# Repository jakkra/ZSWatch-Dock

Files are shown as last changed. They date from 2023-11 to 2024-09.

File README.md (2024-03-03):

# ZSWatch-Dock




## Table of Contents

- [ZSWatch-Dock](#zswatch-dock)
  - [Table of Contents](#table-of-contents)
  - [About](#about)
  - [Configurations](#configurations)
  - [Dock connector](#dock-connector)
  - [Directory structure](#directory-structure)
  - [Purchasing](#purchasing)
  - [Maintainer](#maintainer)

## About

Programming and charging dock for the [ZSWatch](https://github.com/jakkra/ZSWatch).

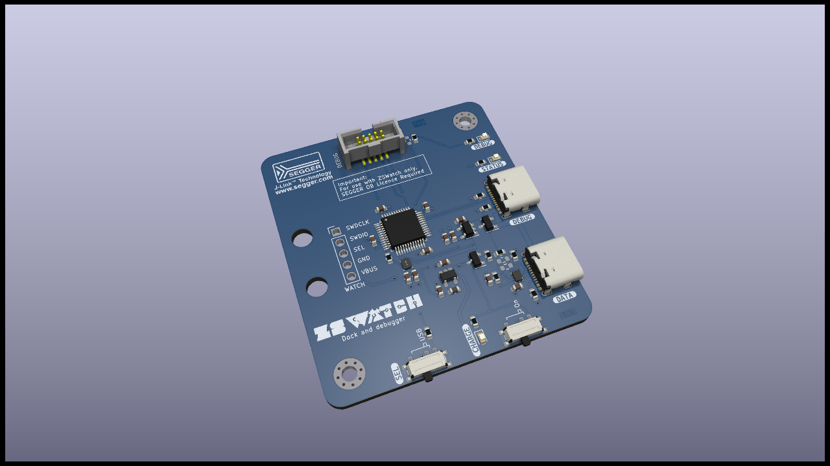
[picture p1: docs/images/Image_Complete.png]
Complete


Please check the [wiki](https://github.com/jakkra/ZSWatch/wiki) for more information about the project.

## Configurations

The dock can be used with an integrated Segger J-Link debugger or with an external Serial Wire Debugger (SWD) with an [10-pol ARM Cortex JTAG SWD](https://developer.arm.com/documentation/101416/0100/Hardware-Description/Target-Interfaces/Cortex-Debug--10-pin-) connector.

## Dock connector

The pinout for the dock connector is shown below.

<table class="tg">
<thead>
  <tr>
    <th class="tg-0pky"></th>
    <th class="tg-0pky">Pin</th>
    <th class="tg-0pky">Description</th>
  </tr>
</thead>
<tbody>
  <tr>
    <td class="tg-0pky" rowspan="5">Dock connector</td>
    <td class="tg-0pky">1</td>
    <td class="tg-0pky">VBUS (+5 V)</td>
  </tr>
  <tr>
    <td class="tg-0pky">2</td>
    <td class="tg-0pky">GND</td>
  </tr>
  <tr>
    <td class="tg-0pky">3</td>
    <td class="tg-0pky">SEL</td>
  </tr>
  <tr>
    <td class="tg-0lax">4</td>
    <td class="tg-0lax">D- / SWDIO</td>
  </tr>
  <tr>
    <td class="tg-0lax">5</td>
    <td class="tg-0lax">D+ / SWDCLK</td>
  </tr>
</tbody>
</table>

| SEL  | Function |
|---|---|
|`LOW` | USB |
|`HIGH`| SWD (Default)  |

## Directory structure

- `cad`: 3D model of the complete PCB
- `docs`: All kind of project documentation
- `project`: KiCad project for the PCB

## Purchasing

Please open `ZSWatch-Dock-navigate.html` and use the files listed under `purchasing` for ordering a PCB.

## Maintainer

- [Daniel Kampert](mailto:daniel.kameprt@kampis-elektroecke.de)
- [Jakob Krantz](mail@jakobkrantz.se)

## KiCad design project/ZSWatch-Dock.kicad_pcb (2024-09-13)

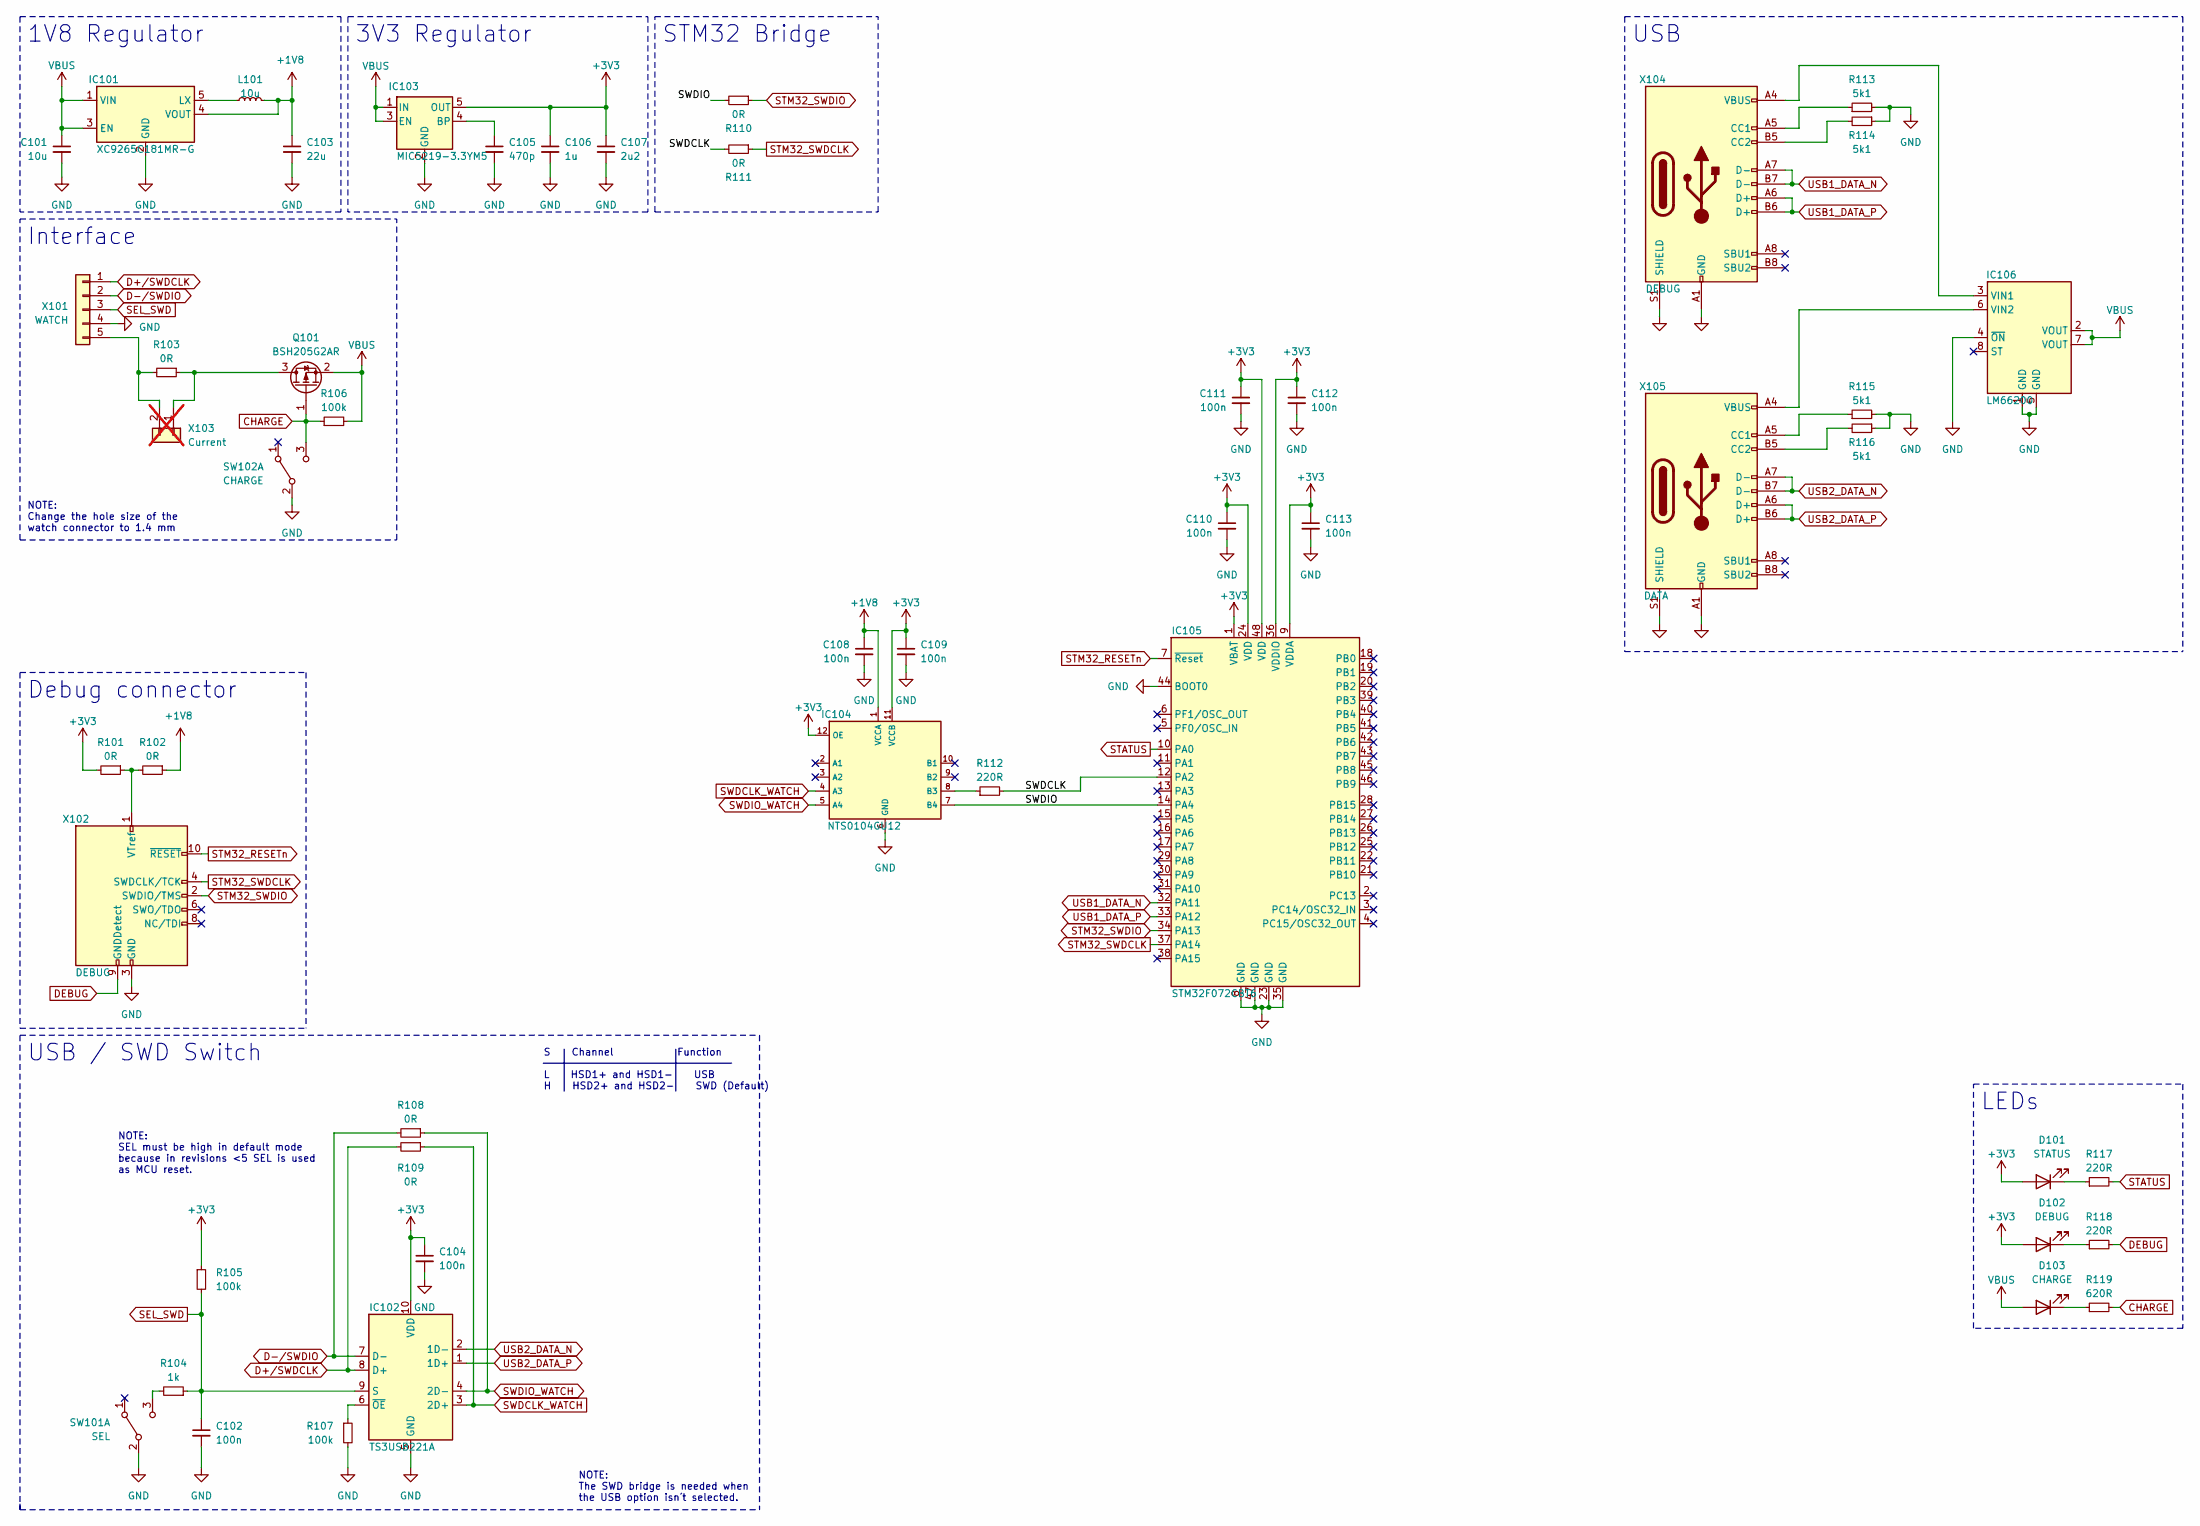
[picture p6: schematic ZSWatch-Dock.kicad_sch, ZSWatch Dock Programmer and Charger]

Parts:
C101: 10u; C_0603_1608Metric
C102, C104, C108, C109, C110, C111, C112, C113: 100n; C_0603_1608Metric
C103: 22u; C_0603_1608Metric
C105: 470p; C_0603_1608Metric
C106: 1u; C_0603_1608Metric
C107: 2u2; C_0603_1608Metric
D101: STATUS; LED_0603_1608Metric
D102: DEBUG; LED_0603_1608Metric
D103: CHARGE; LED_0603_1608Metric
IC101: XC9265C181MR-G; SOT-25-5
IC102: TS3USB221A; UQFN-10_1.55x2.05mm_P0.5mm
IC103: MIC5219-3.3YM5; SOT-23-5
IC104: NTS0104GU12; XQFN-12-1.7x2mm_P0.4mm
IC105: STM32F072CBT6; LQFP-48_7x7mm_P0.5mm
IC106: LM66200; SOT-5X3-8
L101: 10u; L_0603_1608Metric
Q101: BSH205G2AR; SOT-23
R101, R102, R108, R109, R110, R111: 0R; R_0603_1608Metric
R103: 0R; R_0805_2012Metric_Pad1.20x1.40mm_HandSolder
R104: 1k; R_0603_1608Metric
R105, R106, R107: 100k; R_0603_1608Metric
R112, R117, R118: 220R; R_0603_1608Metric
R113, R114, R115, R116: 5k1; R_0603_1608Metric
R119: 620R; R_0603_1608Metric
SW101: SEL; SW_SPDT_PCM12
SW102: CHARGE; SW_SPDT_PCM12
X101: WATCH; PinHeader_1x05_P2.54mm_Vertical
X102: DEBUG; SHF-105-01-L-D-SM-TR
X103: Current; PinHeader_1x02_P2.54mm_Horizontal; not fitted
X104: DEBUG; USB_C_Receptacle_GCT_USB4105-xx-A_16P_TopMnt_Horizontal
X105: DATA; USB_C_Receptacle_GCT_USB4105-xx-A_16P_TopMnt_Horizontal

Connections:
+1V8: C103.1, C108.1, IC101.4 (VOUT), IC104.1 (VCCA), L101.2, R102.1
+3V3: C104.1, C106.1, C107.1, C109.1, C110.1, C111.1, C112.1, C113.1, D101.2 (A), D102.2 (A), IC102.10 (VDD), IC103.5 (OUT), IC104.11 (VCCB), IC104.12 (OE), IC105.1 (VBAT), IC105.9 (VDDA), IC105.24 (VDD), IC105.36 (VDDIO), IC105.48 (VDD), R101.2, R105.1
/SWDCLK: IC105.12 (PA2), R111.2, R112.2
/SWDIO: IC104.7 (B4), IC105.14 (PA4), R110.2
CHARGE: Q101.1 (G), R106.1, R119.2, SW102.3 (C)
D+/SWDCLK: IC102.8 (D+), R109.2, X101.1
D-/SWDIO: IC102.7 (D-), R108.2, X101.2
DEBUG: R118.2, X102.9 (GNDDetect)
GND: C101.2, C102.2, C103.2, C104.2, C105.2, C106.2, C107.2, C108.2, C109.2, C110.2, C111.2, C112.2, C113.2, IC101.2 (GND), IC102.5 (GND), IC103.2 (GND), IC104.6 (GND), IC105.8 (GND), IC105.23 (GND), IC105.35 (GND), IC105.44 (BOOT0), IC105.47 (GND), IC106.1 (GND), IC106.4 (~ON), IC106.5 (GND), R107.2, R113.2, R114.1, R115.2, R116.1, SW101.2 (B), SW102.2 (B), X101.4, X102.3 (GND), X102.5 (GND), X104.A1 (GND), X104.A12 (GND), X104.B1 (GND), X104.B12 (GND), X104.S1 (SHIELD), X105.A1 (GND), X105.A12 (GND), X105.B1 (GND), X105.B12 (GND), X105.S1 (SHIELD)
unnamed: D101.1 (K), R117.1
unnamed: D102.1 (K), R118.1
unnamed: D103.1 (K), R119.1
unnamed: IC101.5 (LX), L101.1
unnamed: IC102.6 (~OE), R107.1
unnamed: C105.1, IC103.4 (BP)
unnamed: IC104.8 (B3), R112.1
unnamed: IC106.3 (VIN1), X104.A4 (VBUS), X104.A9 (VBUS), X104.B4 (VBUS), X104.B9 (VBUS)
unnamed: IC106.6 (VIN2), X105.A4 (VBUS), X105.A9 (VBUS), X105.B4 (VBUS), X105.B9 (VBUS)
unnamed: Q101.3 (D), R103.1, X103.1
unnamed: R104.2, SW101.3 (C)
unnamed: R103.2, X101.5, X103.2
unnamed: R101.1, R102.2, X102.1 (VTref)
unnamed: R113.1, X104.A5 (CC1)
unnamed: R114.2, X104.B5 (CC2)
unnamed: R115.1, X105.A5 (CC1)
unnamed: R116.2, X105.B5 (CC2)
SEL_SWD: C102.1, IC102.9 (S), R104.1, R105.2, X101.3
STATUS: IC105.10 (PA0), R117.2
STM32_RESETn: IC105.7 (~Reset), X102.10 (~RESET)
STM32_SWDCLK: IC105.37 (PA14), R111.1, X102.4 (SWDCLK/TCK)
STM32_SWDIO: IC105.34 (PA13), R110.1, X102.2 (SWDIO/TMS)
SWDCLK_WATCH: IC102.3 (2D+), IC104.4 (A3), R109.1
SWDIO_WATCH: IC102.4 (2D-), IC104.5 (A4), R108.1
USB1_DATA_N: IC105.32 (PA11), X104.A7 (D-), X104.B7 (D-)
USB1_DATA_P: IC105.33 (PA12), X104.A6 (D+), X104.B6 (D+)
USB2_DATA_N: IC102.2 (1D-), X105.A7 (D-), X105.B7 (D-)
USB2_DATA_P: IC102.1 (1D+), X105.A6 (D+), X105.B6 (D+)
VBUS: C101.1, D103.2 (A), IC101.1 (VIN), IC101.3 (EN), IC103.1 (IN), IC103.3 (EN), IC106.2 (VOUT), IC106.7 (VOUT), Q101.2 (S), R106.2

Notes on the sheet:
STM32 Bridge
LEDs
USB / SWD Switch
NOTE: SEL must be high in default mode because in revisions <5 SEL is used as MCU reset.
1V8 Regulator
Interface
NOTE: Change the hole size of the watch connector to 1.4 mm
S Channel Function L HSD1+ and HSD1- USB H HSD2+ and HSD2- SWD (Default)
Debug connector
USB
3V3 Regulator
NOTE: The SWD bridge is needed when the USB option isn´t selected.

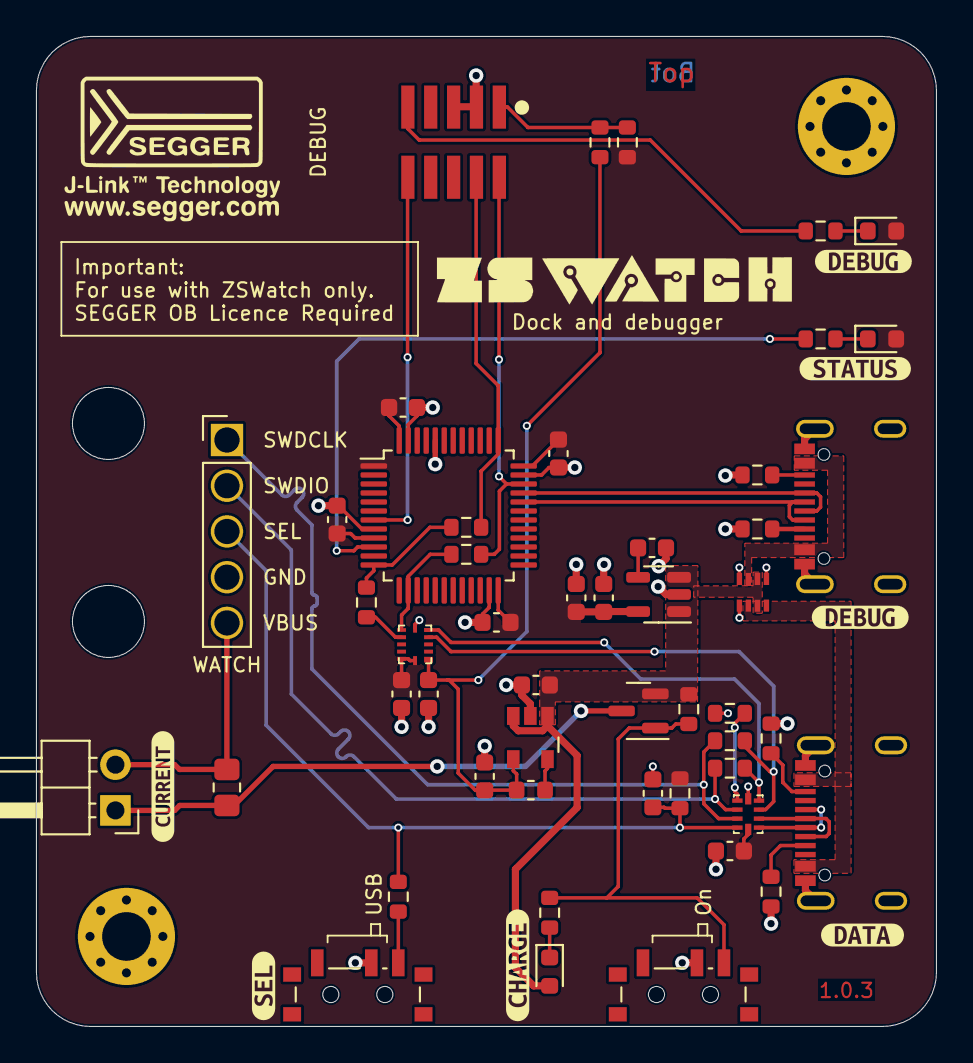
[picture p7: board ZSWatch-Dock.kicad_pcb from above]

Board: 2 copper layers, 50.0 x 55.0 mm, 57 parts (0 on the bottom side), 38 nets.

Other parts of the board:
kibuzzard-65B413A8: G***; kibuzzard-65B413A8
kibuzzard-65B413B7: G***; kibuzzard-65B413B7
kibuzzard-65B41384: G***; kibuzzard-65B41384
kibuzzard-66A144A4: G***; kibuzzard-66A144A4
kibuzzard-6522ABB2: G***; kibuzzard-6522ABB2
kibuzzard-6522ABCA: G***; kibuzzard-6522ABCA
kibuzzard-6525026C: G***; kibuzzard-6525026C

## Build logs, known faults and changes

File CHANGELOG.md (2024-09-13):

# CHANGELOG

## [1.0.4] - 20.07.2024

**Fixed:**

- Fix non ideal footprint for NTS0104GU12

**Added:**

- Add current measurement interface
- Add LM66200 for VBus

**Changed:**

**Removed:**

- Remove protection diode from VBus

## [1.0.3] - 20.07.2024

**Fixed:**

- Fix wrong part number for switching regulator inductor (was 1 uH instead of 10 uH)

**Added:**

- Add QR code with link to GitHub repository
- Add switch to enable / disable charging
- Add workflow for KiBot
- Add additional USB data interface

**Changed:**

- Change PCB color to blue
- Change PCB version to 1.0.3

**Removed:**

- Remove reset line from STM32 to the watch connector

## [1.0.2] - 30.09.2023

**Added:**

- Add jumper to bridge the STM32 processor when not assembled (no license used)
- Add standard STLink V3 connector
- Add dip switch to configure the reset pin for the watch

**Changed:**

- Clean up design
- Change PCB version to 1.0.2

**Removed:**

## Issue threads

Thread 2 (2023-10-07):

Question about STM32_TxD and STM32_RxD in Reset-Config

leezhenghui, 2023-10-07:
Look into the schematic design, I am trying to understand the purpose of getting STM32_T(R)xD in the ZSWatch-Reset-Config section of schematic diagram, but did not get an idea. Any clues about this is really appreciated.

Kampi, 2023-10-07:
Hi @leezhenghui,

the selection switch is a debug placeholder for some additional debug purposes. One possible scenario is to configure the reset pin of the watch as UART Rx pin, UART Tx pin, or GPIO in case RTT isn´t working as expected or for other scenarios. They don´t have a function yet.

leezhenghui, 2023-10-07:
> Hi @leezhenghui,
>
> the selection switch is a debug placeholder for some additional debug purposes. One possible scenario is to configure the reset pin of the watch as UART Rx pin, UART Tx pin, or GPIO in case RTT isn´t working as expected or for other scenarios. The STM32 is working as a VCOM in this scenario (please see `J-Link-OB-STM32F072` in `docs`). But this function isn´t added to the watch firmware for now.

Hi, @Kampi , thanks for your explanation, especially, with a meaningful usage scenario. the design makes sense to me now. :-)

Closed 2023-10-07.

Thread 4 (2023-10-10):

Add jumper to disable power supply (useful to switch between battery and stationary power)

Kampi, 2023-10-10:
**Idea**

VBUS must be disabled to simulate charging or not charging with the dock to the watch.

**Requirements**

Use a low-profile switch to reduce the height of the dock and make it possible to lay the watch on top of it in the future.

Kampi, 2023-10-10:
The first approach

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

Closed 2024-01-29.

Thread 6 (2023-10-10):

Replace 4-pol DIP switch with another solution for switching between USB and SWD

Kampi, 2023-10-10:
**Idea**

Side mounted switch (i. e. https://www.mouser.de/ProductDetail/Alps-Alpine/SSSS710607?qs=6EGMNY9ZYDTXHzgEWhg%252BTw%3D%3D)

**Requirements**

Use a low-profile switch to reduce the height of the dock and make it possible to lay the watch on top of it in the future.

Kampi, 2023-10-10:
The idea is discarded, because we need an additional USB connector too. Debugging and USB at the same time is not possible, so the dock will set the watch to SWD.

Closed 2024-01-29.

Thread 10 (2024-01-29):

Dock casing

Kampi, 2024-01-29:

jakkra, 2024-01-29:
Work in progress. Will finish after dock v1.0.3 is completed.
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

jakkra, 2024-01-30:
Notes for self:
- Add labels for USB
- LED pipes
- Transparent case?

Kampi, 2024-04-06:
@jakkra I think it's done, isn't it?

jakkra, 2024-04-21:
@Kampi I should add two options and upload the files. One for FDM printing and one for Resin. Where one have slots for led pipes

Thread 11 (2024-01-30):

VTarget on the STM32 SWD interface must be switched when using variant with external J-Link

Kampi, 2024-01-30:
In case the reduced variant is used (external J-Link) VTarget must be set to 1.8V because the watch SWD is running on 1.8V.

Best option is to use two 0 Ohm resistors and assemble them according to the variant.

Closed 2024-01-30.

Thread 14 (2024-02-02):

Wrong direction for SWDCLK_WATCH in Schematics

Kampi, 2024-02-02:
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

Closed 2024-02-02.

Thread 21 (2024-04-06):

Testing v1.0.3

Kampi, 2024-04-06:
- [x] Charging switch
- [x] SWD working for watch PCB <rev 5
- [x] Reset working for watch PCB <rev 5
- [x] SWD working for watch PCB rev 5
- [x] USB working for watch PCB rev 5

Closed 2024-04-21.

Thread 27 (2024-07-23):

Add interface for current measurment

Kampi, 2024-07-23:
Add a 2-pin jumper for a current measurement of the watch. A PPK2 can use this interface.

jakkra, 2024-07-24:
Question is if this would show correct readings. Charger can be disabled in SW, but vbus will turn on USB switch. But may still be good for hunting stuff that consumes more than a few uA

Kampi, 2024-07-24:
> Question is if this would show correct readings. Charger can be disabled in SW, but vbus will turn on USB switch. But may still be good for hunting stuff that consumes more than a few uA

That´s true. The USB switch will consume the same amount of power all the time so you have a small offset. IMO it can make sense because otherwise you have to open the watch again and again to measure directly at the battery connector.

jakkra, 2024-07-24:
Yes I agree it still makes sense and is useful

Closed 2024-09-13.

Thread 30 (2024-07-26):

VBUS protection diode doesn´t work with nPM1300

Kampi, 2024-07-26:
Replace it with LM66200

https://www.ti.com/lit/ds/symlink/lm66200.pdf?ts=1703254483263

Closed 2024-09-13.

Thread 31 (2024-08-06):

Replace resistor for CHARGE LED

Kampi, 2024-08-06:
Currently: 13 mA
New: 5 mA

Closed 2024-09-18.

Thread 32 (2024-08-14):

Rework sharing of PCB specifications

Kampi, 2024-08-14:
Screenshots are outdated.

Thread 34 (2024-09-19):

PCB is cut off in rendering

Kampi, 2024-09-19:
The zoom needs to be fixed

Closed 2024-09-19.

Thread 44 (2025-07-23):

Fix wrong pin header for SWD

Kampi, 2025-07-23:

Closed 2025-07-23.

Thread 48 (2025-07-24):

Flip Rx and Tx lines for UART and USB

Kampi, 2025-07-24:

Closed 2025-07-24.

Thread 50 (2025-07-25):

Replace ESD diodes with USBLC6-2P6

Kampi, 2025-07-25:
The current diodes doesn´t work with SWD

Closed 2025-07-26.

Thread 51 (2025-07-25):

"Charge"-Switch does not disable VWatch completely

Kampi, 2025-07-25:
Caused by the ESD diode. Logic is wrong too.

Closed 2025-08-01.

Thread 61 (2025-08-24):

Replace USB connector with edge mounted female USB

Kampi, 2025-08-24:
Using USB cables has too many downsides like selecting the right cable (USB 3.2 or a fully assembled), watching for the right length, watching for the right quality (wire capacitance), etc. So we drop the idea with the cable.

This one
https://www.digikey.de/de/products/detail/jae-electronics/DX07P024AJ5R1500/9169455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

Closed 2025-08-24.

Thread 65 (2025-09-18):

Fix wrong part number for SWD connector

Kampi, 2025-09-18:
[62201021121](https://www.we-online.com/en/components/products/BTB_WR_PHD_1_27_MM_PIN_HEADER#62201021121)

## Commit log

2023-08-21 Initial ZSWatch dock PCB moved from main ZSWatch repo to its own.
    [dock.kicad_pcb, dock.kicad_sch, dock.sch]
2023-08-30 Prepare for production, add production files
    [PCBWay.xls, ZSWatch-Dock.kicad_pcb, ZSWatch-Dock.kicad_sch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]
2023-09-02 - Add missing 3D model for IC1 - Adjust silkscreen on the botton - Add right footprint for debug connector - Generate new production data - Add BOM variants for option with and without J-Link - Add m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
    [PCBWay.xls, ZSWatch-Dock.kicad_pcb, ZSWatch-Dock.kicad_sch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]
2023-09-25 - Reorganize the production files and prepare everything for an easy ordering at PCBWay - Replace schematic symbol for debug connector with standard KiCad part - Enable print part value option in Ger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
    [BOM.xls, PCBWay.xls, ZSWatch-Dock.kicad_pcb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]
2023-09-27 - Sync designators in BOM with Schematics - Update all production files for the configuration with J-Link
    [BOM.xls, ZSWatch-Dock.kicad_pcb, ZSWatch-Dock.kicad_sch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]
2023-09-29 - Add signal names on silkscreen for watch connector - Add production data for variant without J-Link
    [BOM.xls, ZSWatch-Dock.kicad_pcb, ZSWatch-Dock.kicad_sch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]
2023-09-30 - Add blue color to PCB settings - Add surface option to PCB settings
    [ZSWatch-Dock.kicad_pcb]
2023-10-01 - Streamline documentation and production files - Ready to merge
    [BOM.xls, ZSWatch-Dock.kicad_pcb]
2023-10-04 Initialize branch, add dip switch to enable / disable charging
    [ZSWatch-Dock.kicad_pcb, ZSWatch-Dock.kicad_sch]
2023-10-10 - Add QR code with link to GitHub repository - Add switch to enable / disable charging - Remove reset line from STM32 to the watch connector
    [ZSWatch-Dock.kicad_pcb, ZSWatch-Dock.kicad_sch]
2023-10-10 fixup! - Add QR code with link to GitHub repository - Add switch to enable / disable charging - Remove reset line from STM32 to the watch connector
    [ZSWatch-Dock.kicad_sch]
2023-11-30 - Fix wrong part number for inductor
    [BOM.xls, ZSWatch-Dock.kicad_pcb, ZSWatch-Dock.kicad_sch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]
2024-01-25 Add KiBot workflow
    [ZSWatch-Dock.kicad_pcb, ZSWatch-Dock.kicad_sch]
2024-01-25 Remove old production directory
    [BOM.xls]
2024-01-25 Fix wrong KiBot variant names
    [ZSWatch-Dock.kicad_sch]
2024-01-26 Fix wrong logic for SEL pin to align it with watch revisions 1 to 4
2024-01-26 Fix wrong documentation for SEL pin
2024-01-26 Add second USB interface, rename variants
    [ZSWatch-Dock.kicad_pcb, ZSWatch-Dock.kicad_sch]
2024-01-30 - Remove old documentation - Increase drill hole size for watch connector to 1.4 mm - Add mounting holes for a zipper as cable protection - Move mounting holes to a new position into the corners - Se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
    [ZSWatch-Dock.kicad_pcb, ZSWatch-Dock.kicad_sch, ZSWatch-Dock.xlsx]
2024-01-30 Remove 3V3 regulator in minimal variant
    [ZSWatch-Dock.kicad_sch]
2024-01-30 Add jumper to select the right voltage for VTarget on STM32 SWD
    [ZSWatch-Dock.kicad_pcb, ZSWatch-Dock.kicad_sch]
2024-01-30 Move the LEDs a bit into the PCB and increase the space between them so a light pipe can be used
    [ZSWatch-Dock.kicad_pcb]
2024-01-30 Remove watch connector from BOM and from 3D data
    [ZSWatch-Dock.kicad_pcb, ZSWatch-Dock.kicad_sch]
2024-01-30 Move Segger logo back to silkscreen layer
    [ZSWatch-Dock.kicad_pcb]
2024-02-02 Add Segger J-Link OB documentation for STM32
2024-02-02 Fix wrong direction for SWDCLK_WATCH signal in Schematics
    [ZSWatch-Dock.kicad_sch]
2024-02-02 Add note for setting SEL to high per default to support rev <5
    [ZSWatch-Dock.kicad_sch]
2024-02-02 Add debounce capacitor to SEL-Switch
    [ZSWatch-Dock.kicad_pcb, ZSWatch-Dock.kicad_sch]
2024-02-02 Change power supply for CHARGE LED to VBUS
    [ZSWatch-Dock.kicad_pcb, ZSWatch-Dock.kicad_sch]
2024-02-02 Remove STATUS LED in minimal variant
    [ZSWatch-Dock.kicad_sch]
2024-02-02 Add debounce capacitor for SEL pin to reduced variant, remove STATUS LED in reduced variant
    [ZSWatch-Dock.kicad_sch]
2024-02-04 Dock-Connector.drawio eingefügt
2024-02-04 Dock-Connector.drawio aktualisiert
2024-02-07 Cosmetic changes
    [ZSWatch-Dock.kicad_pcb]
2024-02-20 Remove color information for soldermask from project
    [ZSWatch-Dock.kicad_pcb]
2024-03-03 Change PCB color to blue
    [ZSWatch-Dock.kicad_pcb]
2024-04-21 - Replace QR code with area for QR code - Add isolation diode to disconnect both VBUS from each other - Add new logo
    [ZSWatch-Dock.kicad_pcb, ZSWatch-Dock.kicad_sch]
2024-07-23 Upgrade to KiCAD v8
2024-09-13 Initialize branch for rev 4, add connector for current measurement of the watch
    [ZSWatch-Dock.kicad_pcb, ZSWatch-Dock.kicad_sch]
2024-09-13 Replace protection diodes for VBUS with LM66200
    [ZSWatch-Dock.kicad_pcb, ZSWatch-Dock.kicad_sch]
2024-09-13 Fix non ideal footprint for NTS0104GU12
2024-09-13 Change resistor for CHARGE LED to 620 Ohms
    [ZSWatch-Dock.kicad_pcb, ZSWatch-Dock.kicad_sch]
2024-09-19 Update build.yml
    Fix directory structure for PCBWay directory
2024-10-24 Clean up part fields
    [ZSWatch-Dock.kicad_sch]
2024-12-22 Fix typo in 'Order No.' field
    [ZSWatch-Dock.kicad_sch]

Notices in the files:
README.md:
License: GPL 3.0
